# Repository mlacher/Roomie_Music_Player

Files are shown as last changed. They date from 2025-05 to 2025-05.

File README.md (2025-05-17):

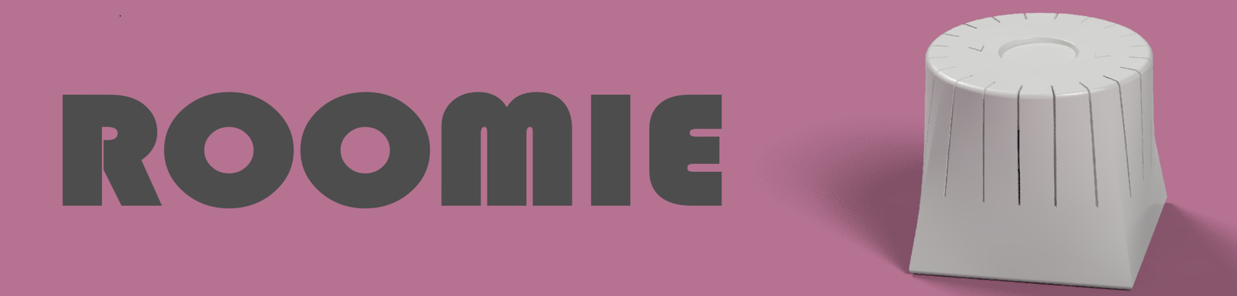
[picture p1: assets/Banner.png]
Roomie Banner
 <!-- Insert a nice rendering or diagram here -->

**Roomie** is a smart home device designed for both kids and adults. It lets users play their favorite music from platforms like Spotify—without needing a smartphone or expensive collectible figures. All it requires are wooden NFC chips (NTAG) that reference a Spotify track or playlist.

---

## 🔧 Features

- 📡 Play music through the built-in speaker or switch to another Spotify-connected device
- 💡 Control playback with NFC chips (Songs, Song forward/backward)
- 📈 Data logging and usage analytics

---

## 🖼️ Rendering / Concept Image

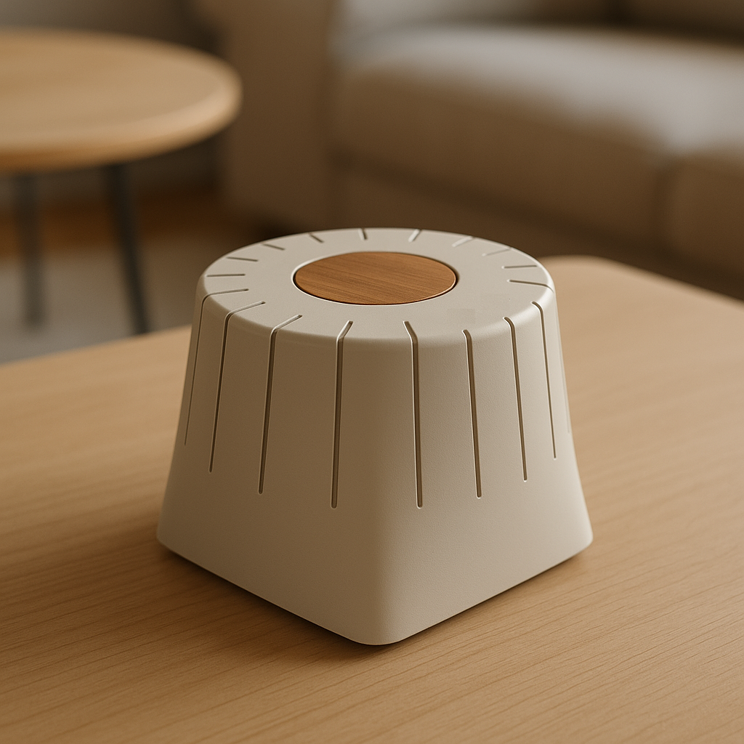
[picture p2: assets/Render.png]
Rendering


---

## Prototype

First prototype using colored 3D printing material (didn´t turn out to be nice):  
Demo

## 📦 Construction/ Bill of Materials

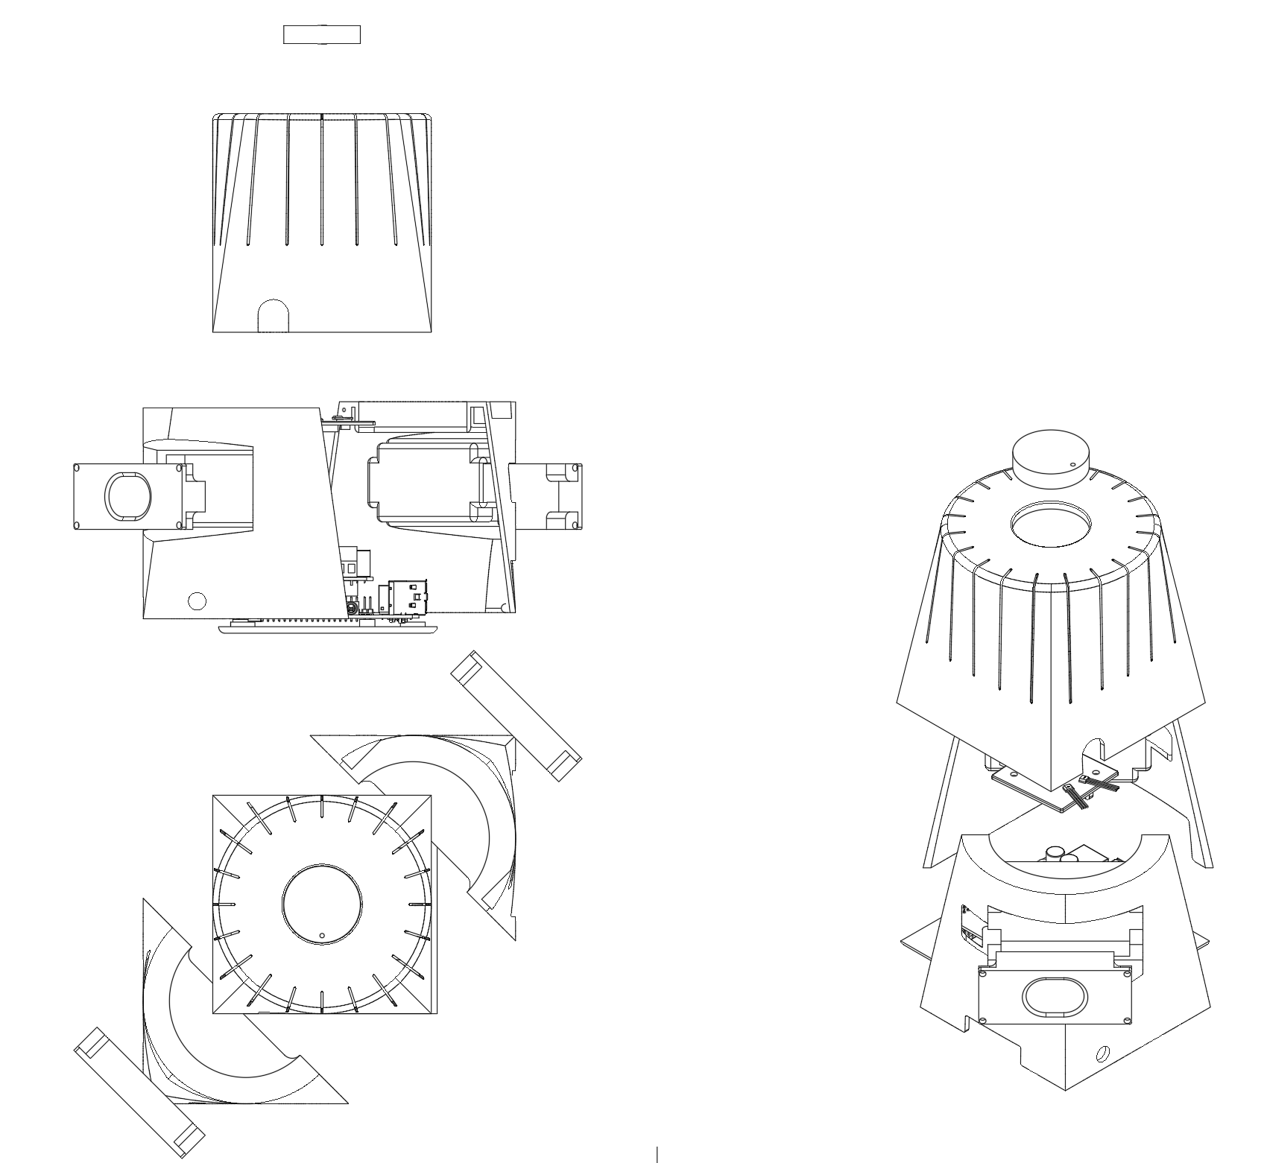
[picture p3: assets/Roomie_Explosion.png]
Explotion


| Component | Quantity | Description | Source / Link |
|---|---|---|---|
| Raspberry Pi 4 | 1 | Core controller | [RaspberryPi.com](https://...) |
| PN532 | 1 | RFID read/write module | [Amazon](https://...) |
| RPI HIFI HAT TAS5713 | 1 | Audio output | [Amazon](https://...) |
| 3D-printed Enclosure | 1 | Custom case designed for Roomie | STL files in `/hardware` folder  |
| LuluDa 3W 8Ω Speaker | 2 | Integrated speaker | [Amazon ](https://www.amazon.de/dp/B08QFTYB9Z?ref=ppx_yo2ov_dt_b_fed_asin_title) |
| A3144 Hall Sensor | 2 | For rotation detection | [Amazon](https://www.amazon.de/dp/B0CZ6QXMZ2?ref=ppx_yo2ov_dt_b_fed_asin_title ) |

> 👉 Full parts list available at [`/docs/BOM.md`](./docs/BOM.md)  
> 👉 For more details and instruction see [instruction](Roomie_Instructions.pdf)

---

## 🧠 System Architecture

```mermaid
graph TD
    PN532 --> |UID| RaspberryPi
    RaspberryPi --> |UID| Cloud
    Cloud --> |Song ID| RaspberryPi
    RaspberryPi --> Speaker

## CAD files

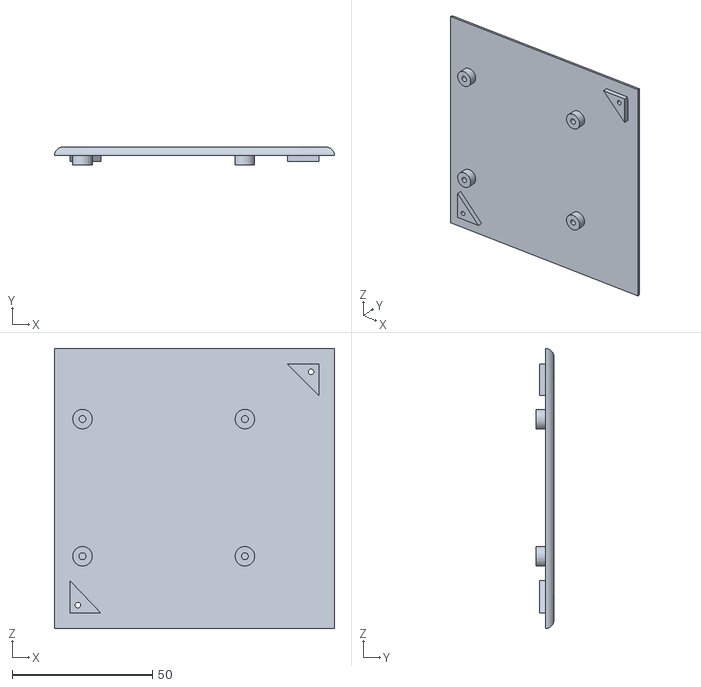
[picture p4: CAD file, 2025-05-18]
hardware/Roomie_1.1_ROOMIE_1.1_Roomie_Bottom_v1.stl
100.0 x 6.40 x 100.0

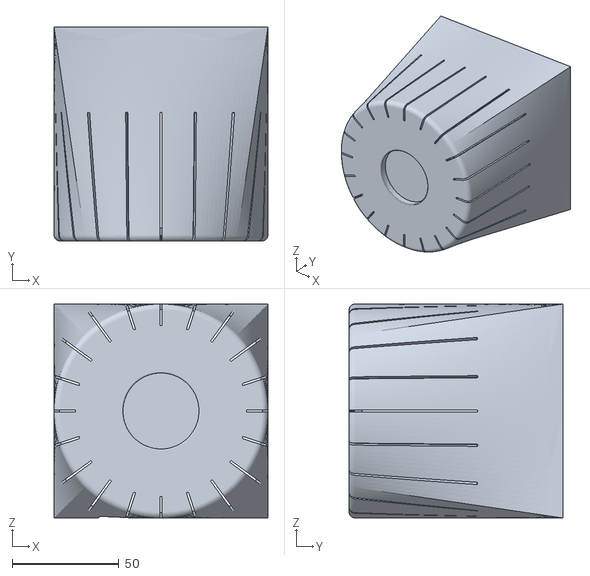
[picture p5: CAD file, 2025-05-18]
hardware/Roomie_1.1_ROOMIE_1.1_Roomie_Cover_v1.stl
100.0 x 100.0 x 100.0

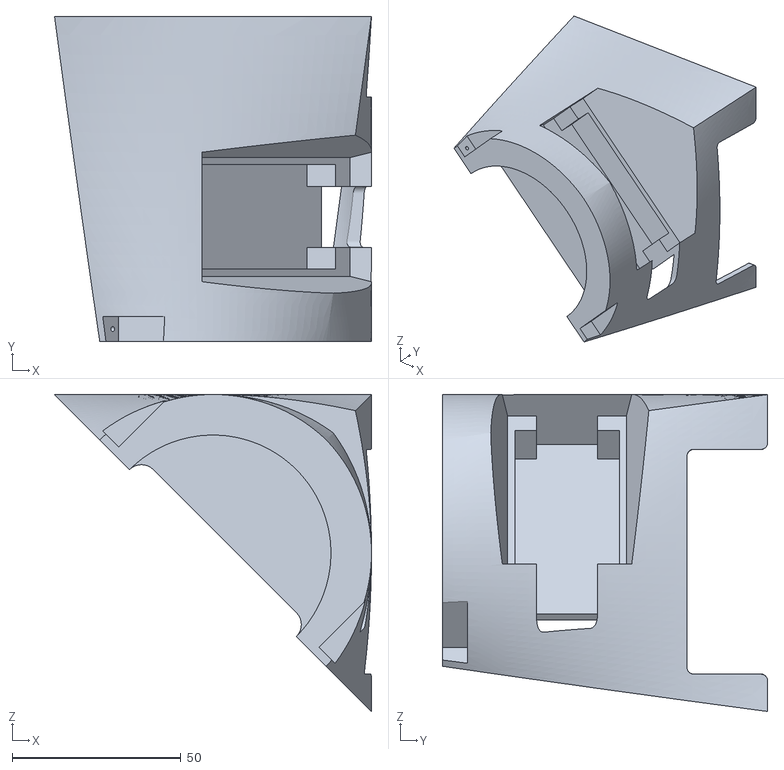
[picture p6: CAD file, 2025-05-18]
hardware/Roomie_1.1_ROOMIE_1.1_Roomie_CoreR_v1.stl
94.0 x 96.5 x 94.0

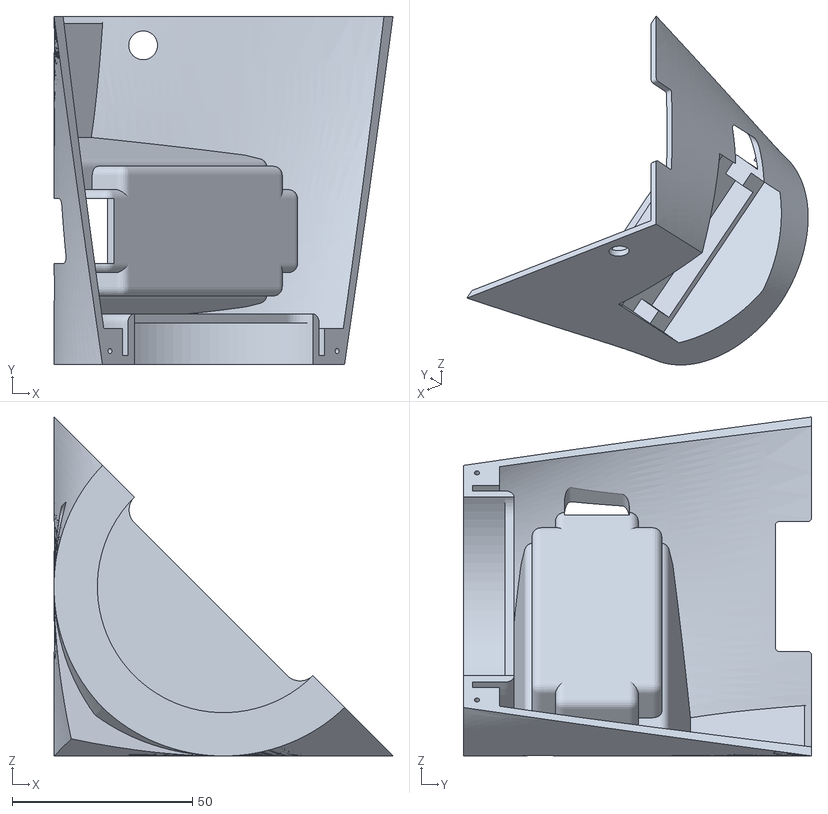
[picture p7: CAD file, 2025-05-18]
hardware/Roomie_1.1_ROOMIE_1.1_Roomie_CoreL_v1.stl
94.0 x 96.5 x 94.0

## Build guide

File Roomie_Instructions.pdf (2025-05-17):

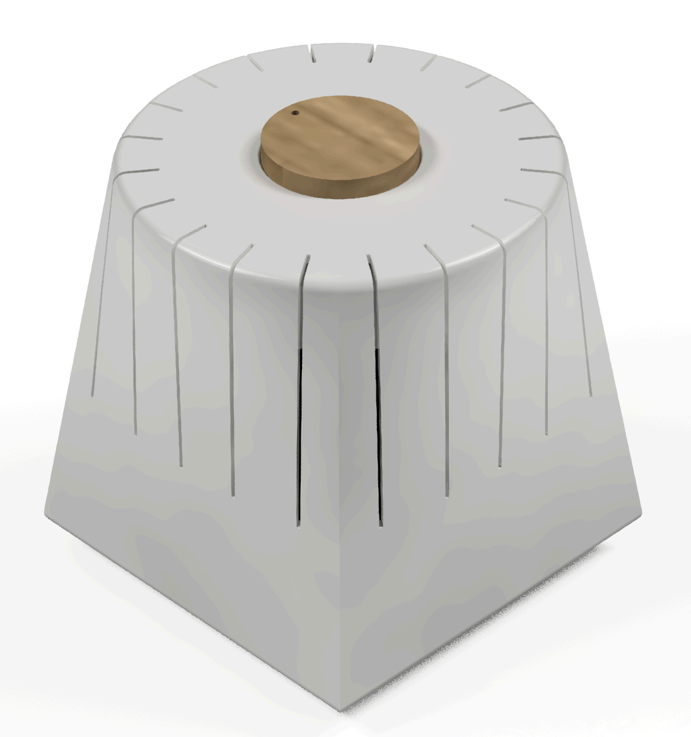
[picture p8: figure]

# Roomie

15.05.2025
─

## Scope

This is a short guide on how to assemble the Roomie speaker and what needs to be done to get the firmware running.

## Description

The way Roomie works is in general straight forward. There are wooden chips with a diameter of 35mm. One chip consists of magnets and a NFC (NTAG) chip with a specific UID. In a database (local) the corresponding spotify playlist link is mapped to the UID. So once the chip is placed in the pocket of the Roomie device, the NFC reader reads the UID and the raspberry pi searches in the database if this UID matches to a spotify URL stored in the database. If valid, this link is handed over to raspotify and played. You could also select a different device to play the music like google nest hub or so, but the reason I built my own speaker is that this way I have more control over the system. (often the spotify app gets shut down by external software to save power, so raspotify would not find a device to play music).
If you remove the Chip from the pocked the music stops, if you turn the Chip inside of the pocked you can forward or revert songs. This is done via the two Hallsensor that are also placed below the pocket and detect the change of the magnet inside of the Chip. As the Sensors are close to each other the direction is detected if one goes LOW and the next one follows soon after.
The database currently has a storage for the mapping of songs to uid, one for available spotify devices and one that shows the history of used chips.
The whole database system is more for fun and totally overengineered, you can get the same result by just storing the playlist link in the NFC NTAG and not using a database at all.

## Hardware

Overall there is not a lot of soldering to do, most of the connection can be done via cables. The only thing that requires a bit of soldering is the 10kohm pull up resistor for the A3144.

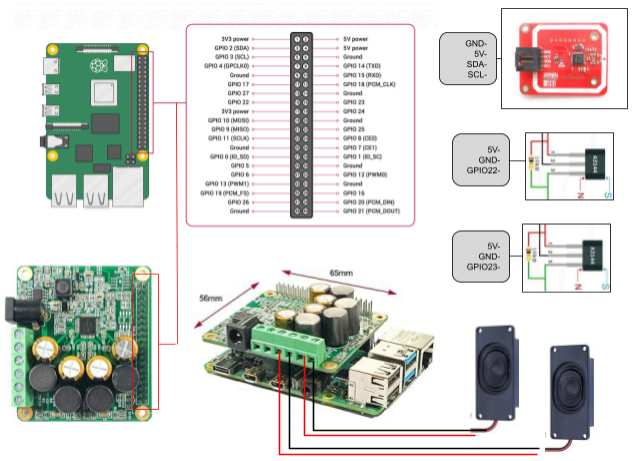
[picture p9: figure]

The whole device is powered via the power jack of the TAS5713 and an external 12V-20V power supply with at least 2A as the HiFi module requires some power.
In the next picture you can see the placement of the parts, the A3144 sensors and the RFID/NFC reader are hot glued on the outer cover of the device to get a defined position to the wooden NFC chip:

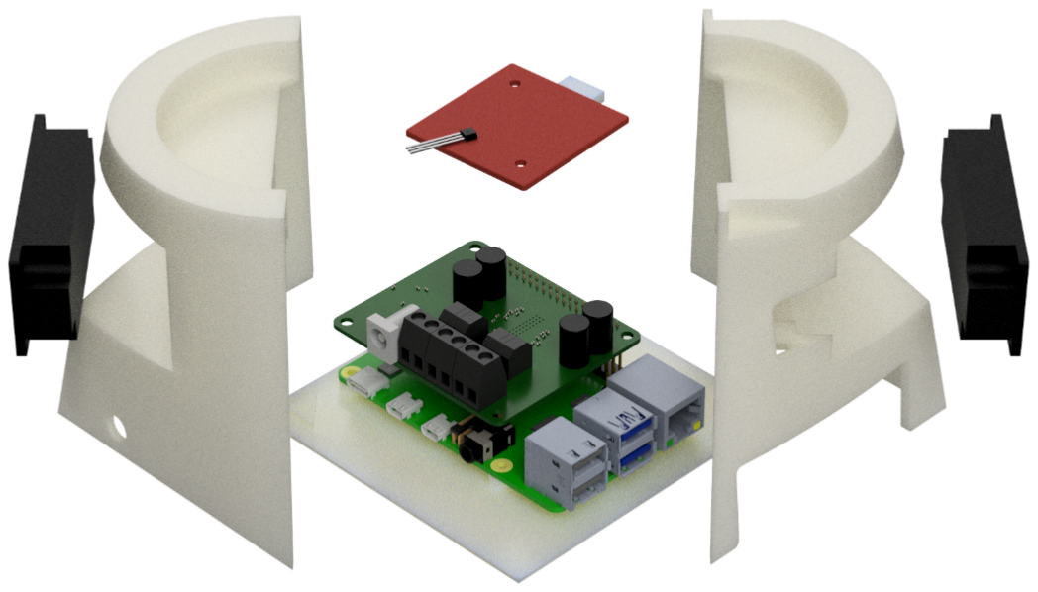
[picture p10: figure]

All plastic parts are 3D printed, used my anycubic Mega 3D printer, it is not super great but does the job.

## Firmware

So first you need to get an OS on the Raspi. I used Raspberry Pi OS without a desktop and controlled the whole device via SSH.
Once the OS is installed on the device and you have access to the raspberry you can start to install raspotify: https://github.com/dtcooper/raspotify
I had quite some troubles getting the HiFi hat running, but I guess I deleted some configs by error, it should work nicely out of the box.
As a last step get the python files from here: https://github.com/mlacher/Roomie_Music_Player

You need to place your spotify credentials in the config.json to get it running.
There are a lot of libraries to install, as I have more hardware than software expertise I am not sure how this can be done automatically but I am sure there is a way-

## Last words

I know this is not half of the information most likely necessary to get the device working, but I am not sure if anyone will ever read this anyways if so please get in contact with me and I will support you the best way possible-

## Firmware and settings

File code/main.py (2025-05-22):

import time
from mariaDB import init_db, devices_db, songs_db, history_db
from pn532_init import init_pn532, read_nfc_with_retry
from config import load_config
import spotipy
from spotipy.oauth2 import SpotifyOAuth
from spotify_control import init_spotify, find_song_by_nfc, music_control
from A3144_sens import check_direction
import logging
import RPi.GPIO as GPIO

# Basic Logging Setup
logging.basicConfig(
    filename='error.txt',  # Log-Datei
    level=logging.INFO,  # Informationslevel
    format='%(asctime)s [%(levelname)s]: %(message)s'
)

def main():
    config = load_config()
    print(config["database"])
    db_connection = init_db(config["database"])
    devices = devices_db(db_connection)
    songs = songs_db(db_connection)
    if not db_connection:
        logging.error("Fehler beim Verbinden mit der Datenbank. Beende das Programm.")
        return

    pn532 = init_pn532()
    sp = init_spotify(config["spotify"], devices[4][0])
    last_uid = None
    last_nfc_check = time.time()
    last_direction_check = time.time()
    last_auto_check = time.time()


    try:
        while True:
            current_time = time.time()

            # Check direction alle 0.05 Sekunden
            if current_time - last_direction_check >= 0.05:
                direction = check_direction()
                if direction == "CCW":
                    music_control(sp, devices[4], None, "previous")
                elif direction == "CW":
                    music_control(sp, devices[4], None, "next")
                last_direction_check = current_time

            # NFC-Check alle 0.1 Sekunden
            if current_time - last_nfc_check >= 0.1:
                uid = read_nfc_with_retry(pn532)
                last_nfc_check = current_time

                if uid is not None:
                    uid_hex = ''.join([f'{x:02X}' for x in uid])
                    print(f"Richtung: {direction}")

                    if uid_hex != last_uid:
                        logging.info(f"Neue UID erkannt: {uid_hex}")
                        song_id = find_song_by_nfc(uid_hex, songs)
                        if song_id:
                            music_control(sp, devices[4], songs[song_id[0]], "new_UID")
                            history_db(db_connection, devices[4], songs[song_id[0]])
                        else:
                            logging.info(f"Keine Zuordnung für UID {uid_hex} gefunden.")

                        last_uid = uid_hex
                        time.sleep(2)
                    else:
                        logging.info("Gleiches Tag wie vorher – ignoriere.")
                        if time.time() - last_auto_check >= 5:
                            music_control(sp, devices[4], songs[song_id[0]], "auto")
                            last_auto_check = time.time()
                else:
                    if last_uid is not None:
                        music_control(sp, devices[4], None, "pause")
                        last_uid = None

    except KeyboardInterrupt:
        logging.info("Programm beendet.")

    finally:
        GPIO.cleanup()


if __name__ == "__main__":
    main()

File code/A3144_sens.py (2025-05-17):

import logging
import RPi.GPIO as GPIO
import time

# GPIO Pins für die Hall-Sensoren
SENSOR_1_PIN = 23
SENSOR_2_PIN = 24
TIME_WINDOW = 1.5  # Zeitfenster in Sekunden
TIME_WINDOW_TRIGGER = 1.5 # Zeitfenster für Trigger in Sekunden

# GPIO Setup
GPIO.setmode(GPIO.BCM)
GPIO.setup(SENSOR_1_PIN, GPIO.IN)
GPIO.setup(SENSOR_2_PIN, GPIO.IN)

last_trigger_1 = None
last_trigger_2 = None

def check_direction():
    global last_trigger_1, last_trigger_2
    current_time = time.time()

    sensor_1_state = GPIO.input(SENSOR_1_PIN)
    sensor_2_state = GPIO.input(SENSOR_2_PIN)

    print(f"S1: {sensor_1_state} | S2: {sensor_2_state}")
    # CW Pattern: Sensor 1 → Sensor 2
    if sensor_1_state == GPIO.LOW and last_trigger_1 is None:
        last_trigger_1 = current_time
        print(f"Trigger 1 gesetzt: {last_trigger_1}")
        print(current_time - last_trigger_1)

    elif sensor_2_state == GPIO.LOW and last_trigger_1:
        # Prüfe, ob Sensor 2 innerhalb des Zeitfensters nach Sensor 1 LOW geht
        print(current_time - last_trigger_1)
        if current_time - last_trigger_1 <= TIME_WINDOW_TRIGGER:
            print("Drehrichtung: CW")
            # Nach einer erfolgreichen Erkennung sofort resetten
            last_trigger_1 = None
            last_trigger_2 = None
            return "CW"
        else:
            last_trigger_1 = None
            last_trigger_2 = None

    # CCW Pattern: Sensor 2 → Sensor 1


    if sensor_2_state == GPIO.LOW and last_trigger_2 is None:
        last_trigger_2 = current_time
        print(f"Trigger 2 gesetzt: {last_trigger_2}")
        print(current_time - last_trigger_2)


    elif sensor_1_state == GPIO.LOW and last_trigger_2:
        # Prüfe, ob Sensor 1 innerhalb des Zeitfensters nach Sensor 2 LOW geht
        print(current_time - last_trigger_2)

        if current_time - last_trigger_2 <= TIME_WINDOW_TRIGGER:
            print("Drehrichtung: CCW")
            last_trigger_1 = None
            last_trigger_2 = None
            return "CCW"
        else:
            last_trigger_1 = None
            last_trigger_2 = None

    # Reset both triggers if both sensors are HIGH and within the time window
    if (sensor_1_state == GPIO.HIGH and sensor_2_state == GPIO.HIGH and 
        ((last_trigger_1 and current_time - last_trigger_1 >= TIME_WINDOW) or 
         (last_trigger_2 and current_time - last_trigger_2 >= TIME_WINDOW))): 
        last_trigger_1 = None
        last_trigger_2 = None

    return None


def main_loop():
    try:
        while True:
            check_direction()
            time.sleep(0.1)
    except KeyboardInterrupt:
        print("Beende Programm")
    finally:
        GPIO.cleanup()

if __name__ == "__main__":
    main_loop()

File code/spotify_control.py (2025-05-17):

import time
import random
import os
import spotipy
from spotipy.oauth2 import SpotifyOAuth
import subprocess
import logging 

shuffle_list = []
current_index = -1
last_play_mode = None

import subprocess

def restart_raspotify():
    try:
        subprocess.run(['sudo', 'systemctl', 'restart', 'raspotify'], check=True)
        print("Raspotify neu gestartet")
    except subprocess.CalledProcessError as e:
        print(f"Fehler beim Neustarten von Raspotify: {e}")





# Initialisierung von Spotify

def init_spotify(sp_config, device_name):
    attempt = 0
    sp = None
    while attempt < 3:
        try:
            sp = spotipy.Spotify(auth_manager=SpotifyOAuth(
                client_id=sp_config["client_id"],
                client_secret=sp_config["client_secret"],
                redirect_uri=sp_config["redirect_uri"],
                scope=sp_config['scope']
            ))
            devices = sp.devices()['devices']
            for device in devices:
                if device['name'] == device_name:
                    print(f"Gerät {device_name} gefunden")
                    return sp
            print(f"Gerät {device_name} nicht gefunden. Versuche erneut...")
            restart_raspotify()
            time.sleep(5)
        except Exception as e:
            print(f"Fehler bei der Spotify-Initialisierung: {e}")
        attempt += 1

    logging.error("Gerät nicht gefunden. Initialisierung fehlgeschlagen.")
    return None

# Geräte abrufen

def get_available_devices(sp):
    devices = sp.devices()['devices']
    return devices

# Playlist-URIs abrufen

def get_track_uris_from_playlist(sp, playlist_id, shuffle=False):
    track_uris = []
    try:
        results = sp.playlist_tracks(playlist_id)
        while results:
            for item in results['items']:
                track = item['track']
                if track:
                    track_uris.append(track['uri'])
            if results['next']:
                results = sp.next(results)
            else:
                break
    except Exception as e:
        logging.info(f"Fehler beim Laden der Playlist: {e}")
    if shuffle:
        random.shuffle(track_uris)
    return track_uris

# NFC-Song Suche

def find_song_by_nfc(nfc_id, song_list):
    for index, song in enumerate(song_list):
        if song[0] == nfc_id:
            return index, song
    return None, None

# Music Control Funktion

def music_control(sp, device_data, song_data, play_mode):
    global shuffle_list, current_index, last_play_mode
    device_id = device_data[1]
    playlist_flag = song_data[4] if song_data else 0

    try:
        if play_mode != last_play_mode:
            # Playlist-Modus aktivieren
            if play_mode == "new_UID" and song_data:
                track_id = song_data[3]
                if playlist_flag == 1:
                    # Playlist laden und shufflen
                    shuffle_list = get_track_uris_from_playlist(sp, track_id, shuffle=True)
                    if shuffle_list:
                        current_index = 0
                        sp.start_playback(device_id=device_id, uris=[shuffle_list[current_index]])
                        logging.info(f"Starte Shuffle-Track: {shuffle_list[current_index]}")
                else:
                    # Einzelner Song
                    track_uri = f"spotify:track:{track_id.strip()}"
                    shuffle_list = [track_uri]
                    current_index = 0
                    sp.start_playback(device_id=device_id, uris=[track_uri])
                    logging.info(f"Spiele Einzelsong: {track_uri}")

            elif play_mode == "pause":
                sp.pause_playback(device_id=device_id)
                logging.info("Wiedergabe pausiert.")

            elif play_mode == "play":
                sp.start_playback(device_id=device_id)
                logging.info("Wiedergabe gestartet.")

            elif play_mode == "next":
                if shuffle_list and current_index < len(shuffle_list) - 1:
                    current_index += 1
                    sp.start_playback(device_id=device_id, uris=[shuffle_list[current_index]])
                    logging.info(f"Nächster Shuffle-Track: {shuffle_list[current_index]}")
                else:
                    logging.info("Ende der Shuffle-Liste erreicht.")

            elif play_mode == "previous":
                if shuffle_list and current_index > 0:
                    current_index -= 1
                    sp.start_playback(device_id=device_id, uris=[shuffle_list[current_index]])
                    logging.info(f"Vorheriger Shuffle-Track: {shuffle_list[current_index]}")
                else:
                    logging.info("Am Anfang der Shuffle-Liste.")

        # Automatisches Weiterspielen unabhängig vom Playmode
        elif play_mode == "auto" and shuffle_list:
            current_track = sp.current_playback()
            if current_track and current_track.get("is_playing"):
                track_progress = current_track["progress_ms"]
                track_duration = current_track["item"]["duration_ms"]

                if track_progress >= track_duration - 1500:
                    if current_index < len(shuffle_list) - 1:
                        current_index += 1
                        sp.start_playback(device_id=device_id, uris=[shuffle_list[current_index]])
                        logging.info(f"Automatisch zum nächsten Shuffle-Track gewechselt: {shuffle_list[current_index]}")
                    else:
                        logging.info("Ende der Shuffle-Liste erreicht.")
            elif not current_track:
                logging.info("Keine Wiedergabe aktiv. Playlist wird fortgesetzt...")
                if shuffle_list and current_index < len(shuffle_list) - 1:
                    current_index += 1
                    sp.start_playback(device_id=device_id, uris=[shuffle_list[current_index]])
                    logging.info(f"Fortgesetzt mit: {shuffle_list[current_index]}")
                else:
                    logging.info("Playlist beendet.")

        # Aktualisierung des letzten Playmode-Status
        last_play_mode = play_mode

    except Exception as e:
        logging.error(f"Fehler in music_control: {e}")

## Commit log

2025-05-18 modified: config.py modified: error.txt modified: log.txt modified: main.py modified: nohup.out modified: spotify_auth_check.py modified: tests/__pycache__/test_pn532_init.cpython-311-pytest-8.3.5.py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
    [main.py, spotify_auth_check.py]
2025-05-22 Changes to be committed: reduce spotify api calls to avoid rate limit modified: code/.cache modified: code/__pycache__/config.cpython-311.pyc modified: code/config.py modified: code/error.txt modifie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
    [main.py]
